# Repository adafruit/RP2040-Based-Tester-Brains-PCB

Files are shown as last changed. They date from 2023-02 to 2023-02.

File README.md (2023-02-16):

## Adafruit RP2040 Based Tester Brains PCB



PCB files for the Adafruit RP2040 Based Tester Brains. 

Format is EagleCAD schematic and board layout

### Description

This board is what we use internally at Adafruit to program and test boards with microcontrollers on them. 
   * An [RP2040 Pico](https://www.adafruit.com/product/5525) (or perhaps PicoW?) is used to run the test software
   * [Use a 16x2 LCD (ideally RGB backlight)](https://www.adafruit.com/product/398) for display output with color feedback such as green for pass, red for fail. RGB backlight is WS2811-controlled. Don't forget to set the contrast pot on first usage.
   * Serial1 hardware UART has RX/TX pin switch to flip directions
   * 1.9" TFT connector is placed but hasn't been tested or used yet
   * Piezo buzzer can be used for audible feedback alerts
   * STEMMA QT I2C port
   * Big reset button
   * Firmware files can be stored on MicroSD card which is slotted in. 
   * Connect the right hand side, either the 0.1" header or 18-pin EYESPI-like FPC connector to the device-under-test jig which can be different for each product. 
   * [USB Host testing is done with bitbang PIO support in TinyUSB](https://github.com/adafruit/Adafruit_TinyUSB_Arduino), USB 5V power can be turned on / off 
   * Use Philhower RP2040 core for programming
   * The RP2040 brains can perform ESP32 programming, RP2040-via-USB, AVR ICSP/UPDI, or SWD DAP. [See the TestBed library for some examples.](https://github.com/adafruit/Adafruit_TestBed)

**THIS IS NOT AN ADAFRUIT PRODUCT, IT IS COMPLETELY AND UTTERLY UNSUPPORTED. THERE ARE NO PLANS/ETA FOR MANUFACTURING, STOCKING OR SUPPORTING. DO NOT ASK FOR SUPPORT OR ASSISTANCE. THIS INCLUDES ASKING US FOR BOM, SOURCING OR ASSEMBLY HELP. WE DON'T GUARANTEE IT WORKS FOR YOU OR AT ALL AND ARE ONLY PUBLISHING IT IN THE HOPES THAT IT IS USEFUL FOR SOMEONE WHO DOES NOT NEED SUPPORT OR ASSISTANCE IN USING IT!**

rp2040 programming an rp2040 ~ flash inception (https://www.youtube.com/watch?v=sjl7aVK2Q2U)

The Desk of Ladyada - RP2040 Tester bringup & LCD QT revisions (https://www.youtube.com/watch?v=3gakI1QBvXw)

Desk of Ladyada - Teensy Tester Redesigned to RP2040 Pico (https://www.youtube.com/live/iSWNARXhVM0?feature=share&t=951)

### License

Adafruit invests time and resources providing this open source design, please support Adafruit and open-source hardware by purchasing products from [Adafruit](https://www.adafruit.com)!

Designed by Limor Fried/Ladyada for Adafruit Industries.

Creative Commons Attribution/Share-Alike, all text above must be included in any redistribution. 
See license.txt for additional details.

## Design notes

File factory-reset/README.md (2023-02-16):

## Factory Reset file - RP2040 based tester brains

This is the factory reset file for the RP2040 based tester brains. Drag it onto the RP2040 Pico to verify the LCD, backlight, microSD, QT port all work. Adjust contrast pot till you see text on the LCD. Open serial console to see debug output.

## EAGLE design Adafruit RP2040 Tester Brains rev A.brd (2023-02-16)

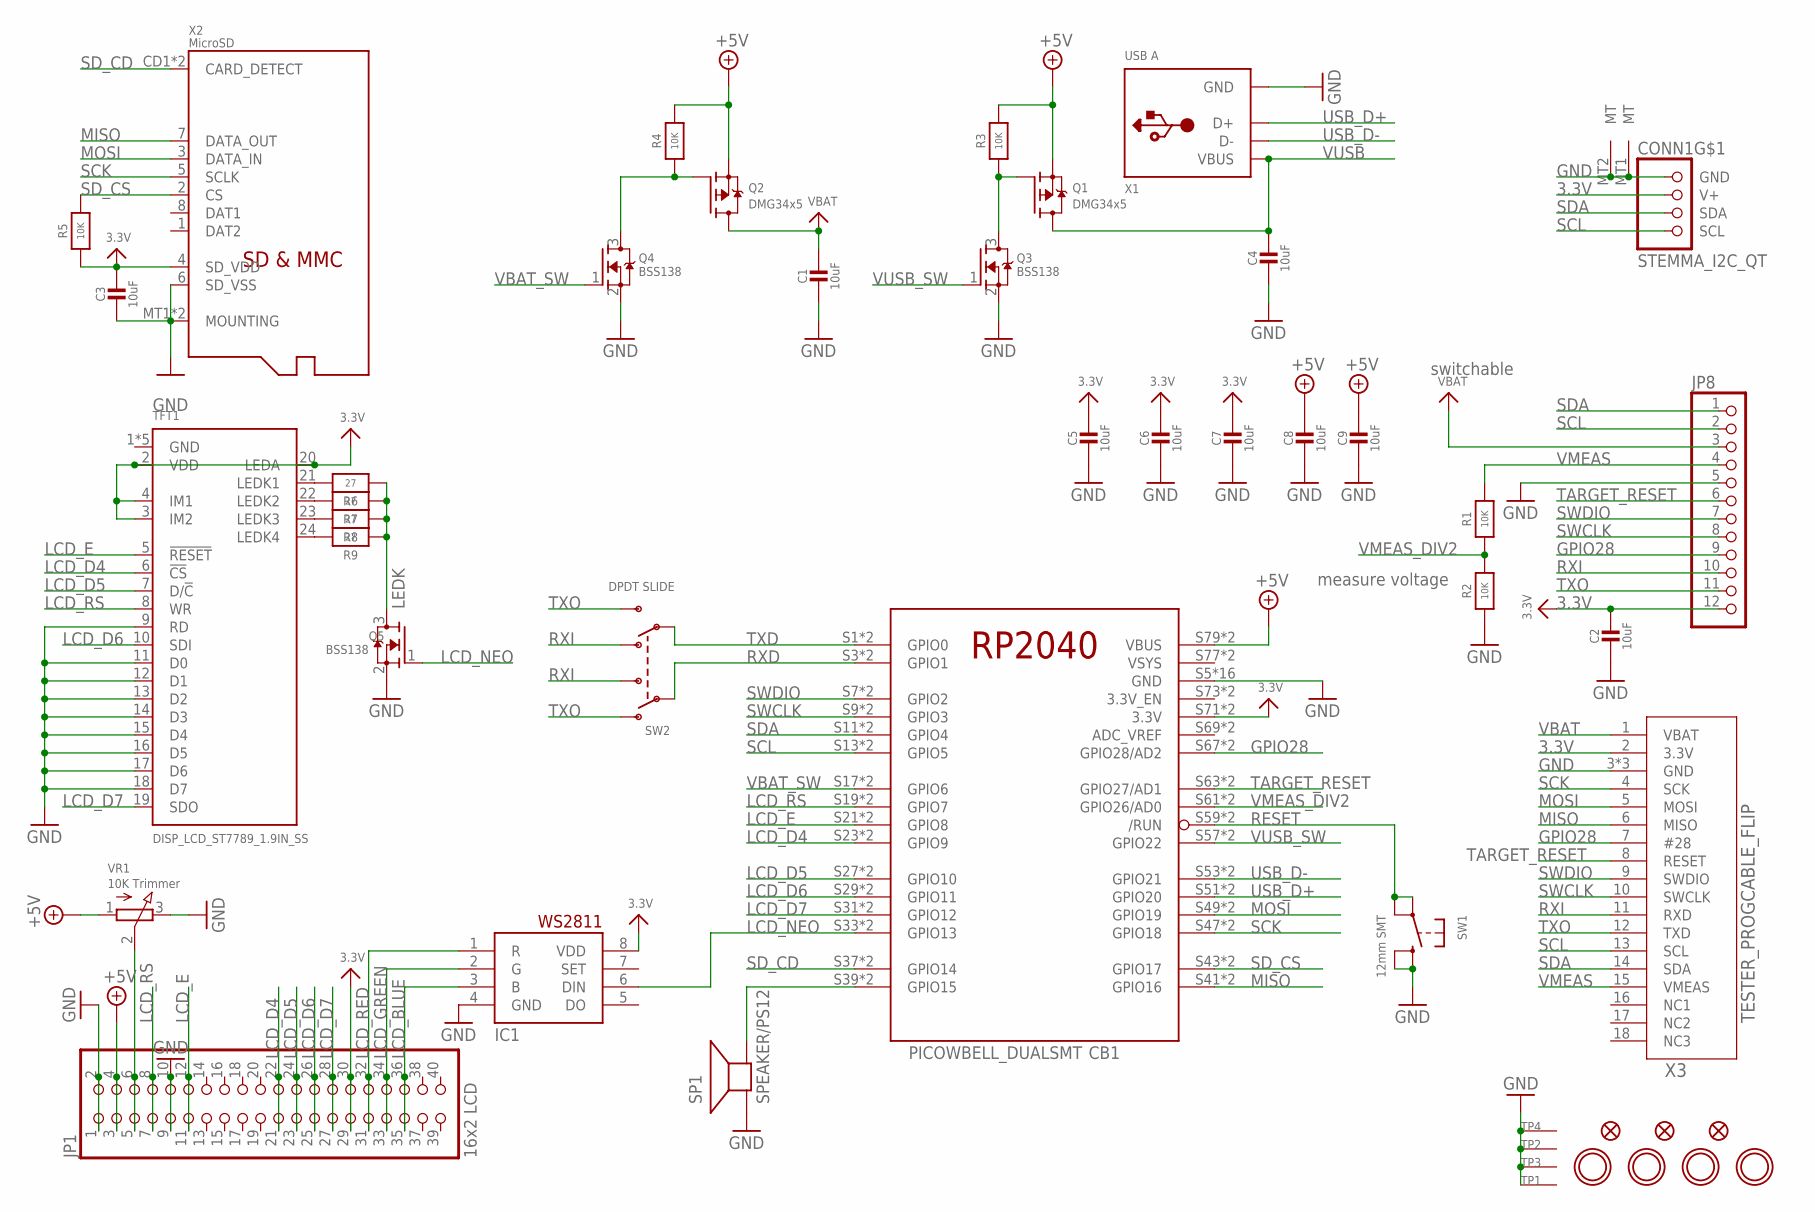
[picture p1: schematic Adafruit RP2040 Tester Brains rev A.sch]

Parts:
C1, C2, C3, C4, C5, C6, C7, C8, C9: 10uF; 0805-NO
CB1: PICOWBELL_DUALSMT
CONN1: STEMMA_I2C_QT; JST_SH4
FID1, FID2, FID3: FIDUCIAL_1MM
IC1: WS2811-SOP8; SO08-SKINNYPADS
JP1: 16x2 LCD; 2X20_SMT_MALE
JP8: HEADER-1X12OVAL; 1X12_OVAL
Q1, Q2: DMG34x5; SOT23-WIDE
Q3, Q4, Q5: BSS138; SOT23-WIDE
R1, R2, R3, R4, R5: 10K; 0603-NO
R6, R7, R8, R9: 27; 0603-NO; LCSC C25190
SP1: SPEAKER/PS12; PS12
SW1: 12mm SMT; B3F-40XX-SMT
SW2: DPDT SLIDE; EG1390; LCSC C318999
TFT1: DISP_LCD_ST7789_1.9IN_SS; TFT_1.9IN_170X320_30P_SS
TP1, TP2, TP3, TP4: SEWTAP_SMTNUTM3; SMT_NUT_3MM
U$7, U$8, U$9, U$10: MOUNTINGHOLE3.0THIN; MOUNTINGHOLE_3.0_PLATEDTHIN
VR1: 10K Trimmer; TRIMPOT_BOURNS_TC33X-2
X1: USB A; USB_HOST-SMT
X2: MicroSD; MICROSD
X3: TESTER_PROGCABLE_FLIP; FPC_0.5MM_18PIN

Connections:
3.3V: C2.1, C3.1, C5.1, C6.1, C7.1, CB1.S71 (3.3V), CB1.S72 (3.3V), CONN1.2 (V+), IC1.8 (VDD), JP1.29, JP1.30, JP8.12, R5.1, TFT1.2 (VDD), TFT1.3 (IM2), TFT1.4 (IM1), TFT1.20 (LEDA), X2.4 (SD_VDD), X3.2 (3.3V)
!VBAT_SW1: Q2.1 (G), Q4.3 (D), R4.1
!VBAT_SW2: Q1.1 (G), Q3.3 (D), R3.1
+5V: C8.1, C9.1, CB1.S79 (VBUS), CB1.S80 (VBUS), JP1.3, JP1.4, Q1.2 (S), Q2.2 (S), R3.2, R4.2, VR1.1 (A)
GND: C1.2, C2.2, C3.2, C4.2, C5.2, C6.2, C7.2, C8.2, C9.2, CB1.S5 (GND), CB1.S6 (GND), CB1.S15 (GND), CB1.S16 (GND), CB1.S25 (GND), CB1.S26 (GND), CB1.S35 (GND), CB1.S36 (GND), CB1.S45 (GND), CB1.S46 (GND), CB1.S55 (GND), CB1.S56 (GND), CB1.S65 (GND), CB1.S66 (GND), CB1.S75 (GND), CB1.S76 (GND), CONN1.1 (GND), CONN1.MT1 (MT), CONN1.MT2 (MT), IC1.4 (GND), JP1.1, JP1.2, JP1.9, JP1.10, JP8.5, Q3.2 (S), Q4.2 (S), Q5.2 (S), R2.1, SP1.P$1 (+), SW1.P$3 (S), SW1.P$4 (S1), TFT1.1 (GND), TFT1.9 (RD), TFT1.11 (D0), TFT1.12 (D1), TFT1.13 (D2), TFT1.14 (D3), TFT1.15 (D4), TFT1.16 (D5), TFT1.17 (D6), TFT1.18 (D7), TFT1.25 (GND), TFT1.30 (GND), TFT1.MNT1 (GND), TFT1.MNT2 (GND), TP1.P$1, TP2.P$1, TP3.P$1, TP4.P$1, VR1.3 (E), X1.GND, X2.6 (SD_VSS), X2.MT1 (MOUNTING), X2.MT2 (MOUNTING), X3.3 (GND), X3.SUPPORT1 (GND), X3.SUPPORT2 (GND)
GPIO28: CB1.S67 (GPIO28/AD2), CB1.S68 (GPIO28/AD2), JP8.9, X3.7 (#28)
LCD_BLUE: IC1.3 (B), JP1.35, JP1.36
LCD_D4: CB1.S23 (GPIO9), CB1.S24 (GPIO9), JP1.21, JP1.22, TFT1.6 (!CS)
LCD_D5: CB1.S27 (GPIO10), CB1.S28 (GPIO10), JP1.23, JP1.24, TFT1.7 (D/!C)
LCD_D6: CB1.S29 (GPIO11), CB1.S30 (GPIO11), JP1.25, JP1.26, TFT1.10 (SDI)
LCD_D7: CB1.S31 (GPIO12), CB1.S32 (GPIO12), JP1.27, JP1.28, TFT1.19 (SDO)
LCD_E: CB1.S21 (GPIO8), CB1.S22 (GPIO8), JP1.11, JP1.12, TFT1.5 (!RESET)
LCD_GREEN: IC1.2 (G), JP1.33, JP1.34
LCD_NEO: CB1.S33 (GPIO13), CB1.S34 (GPIO13), IC1.6 (DIN), Q5.1 (G)
LCD_RED: IC1.1 (R), JP1.31, JP1.32
LCD_RS: CB1.S19 (GPIO7), CB1.S20 (GPIO7), JP1.7, JP1.8, TFT1.8 (WR)
LEDK: Q5.3 (D), R6.1, R7.1, R8.1, R9.1
MISO: CB1.S41 (GPIO16), CB1.S42 (GPIO16), X2.7 (DATA_OUT), X3.6 (MISO)
MOSI: CB1.S49 (GPIO19), CB1.S50 (GPIO19), X2.3 (DATA_IN), X3.5 (MOSI)
unnamed: CB1.S39 (GPIO15), CB1.S40 (GPIO15), SP1.P$2 (-)
unnamed: R6.2, TFT1.21 (LEDK1)
unnamed: R7.2, TFT1.22 (LEDK2)
unnamed: R8.2, TFT1.23 (LEDK3)
unnamed: R9.2, TFT1.24 (LEDK4)
unnamed: JP1.5, JP1.6, VR1.2 (S)
RESET: CB1.S59 (/RUN), CB1.S60 (/RUN), SW1.P$1, SW1.P$2 (P1)
RXD: CB1.S3 (GPIO1), CB1.S4 (GPIO1), SW2.P1
RXI: JP8.10, SW2.O2, SW2.S1, X3.11 (RXD)
SCK: CB1.S47 (GPIO18), CB1.S48 (GPIO18), X2.5 (SCLK), X3.4 (SCK)
SCL: CB1.S13 (GPIO5), CB1.S14 (GPIO5), CONN1.4 (SCL), JP8.2, X3.13 (SCL)
SDA: CB1.S11 (GPIO4), CB1.S12 (GPIO4), CONN1.3 (SDA), JP8.1, X3.14 (SDA)
SD_CD: CB1.S37 (GPIO14), CB1.S38 (GPIO14), X2.CD1 (CARD_DETECT), X2.CD2 (CARD_DETECT)
SD_CS: CB1.S43 (GPIO17), CB1.S44 (GPIO17), R5.2, X2.2 (CS)
SWCLK: CB1.S9 (GPIO3), CB1.S10 (GPIO3), JP8.8, X3.10 (SWCLK)
SWDIO: CB1.S7 (GPIO2), CB1.S8 (GPIO2), JP8.7, X3.9 (SWDIO)
TARGET_RESET: CB1.S63 (GPIO27/AD1), CB1.S64 (GPIO27/AD1), JP8.6, X3.8 (RESET)
TXD: CB1.S1 (GPIO0), CB1.S2 (GPIO0), SW2.P2
TXO: JP8.11, SW2.O1, SW2.S2, X3.12 (TXD)
USB_D+: CB1.S51 (GPIO20), CB1.S52 (GPIO20), X1.D+
USB_D-: CB1.S53 (GPIO21), CB1.S54 (GPIO21), X1.D-
VBAT: C1.1, JP8.3, Q2.3 (D), X3.1 (VBAT)
VBAT_SW: CB1.S17 (GPIO6), CB1.S18 (GPIO6), Q4.1 (G)
VMEAS: JP8.4, R1.2, X3.15 (VMEAS)
VMEAS_DIV2: CB1.S61 (GPIO26/AD0), CB1.S62 (GPIO26/AD0), R1.1, R2.2
VSYS: CB1.S77 (VSYS), CB1.S78 (VSYS)
VUSB: C4.1, Q1.3 (D), X1.VBUS
VUSB_SW: CB1.S57 (GPIO22), CB1.S58 (GPIO22), Q3.1 (G)

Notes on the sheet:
switchable
measure voltage

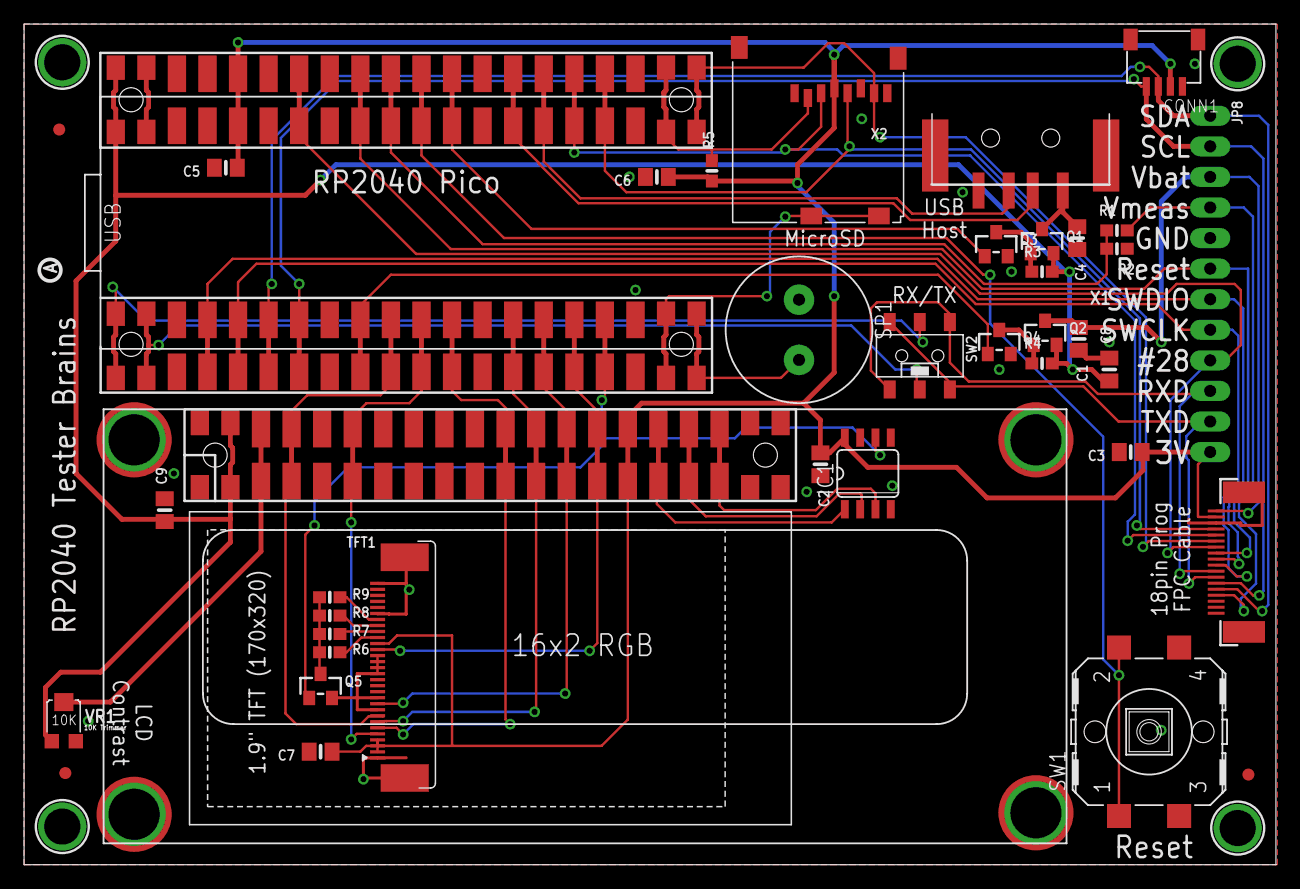
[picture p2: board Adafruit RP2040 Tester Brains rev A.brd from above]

Board: 2 copper layers, 104.0 x 69.8 mm, 48 parts (0 on the bottom side), 47 nets.

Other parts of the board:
U$13: PCBFEAT-REV-040

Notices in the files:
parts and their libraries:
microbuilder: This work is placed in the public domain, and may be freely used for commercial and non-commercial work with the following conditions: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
